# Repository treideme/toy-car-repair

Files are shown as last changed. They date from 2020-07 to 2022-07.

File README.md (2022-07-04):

# Mercedes Toy Repair

This repo contains schematics, drawings, and firmware of the controller
for my sons broken Mercedes.

See [my blogpost](https://www.reidemeister.com/?p=465) for more information.

---- 
Pull requests are welcome. For major changes, please open an issue first to discuss what you would like to change.

## License
[MIT](LICENSE.md)

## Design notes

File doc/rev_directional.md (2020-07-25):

# Reverse Engineering the Directional Controller

This module seems to take care of the directional control of the
car. 

Directional Controller

It has three buttons. The center button disables directional
control. The front and the back button set the direction.

There are two LEDs next to the buttons that indicate the direction.

The board is supplied through J1. The pinout, starting from the J1
marking seems to be as follows.

| Pin # | Signal | Level | Cable Color
|---|---|---|---
| 1 | GND | 0 V | Black
| 2 | Power  | 5 V | White
| 3 | Backward | 0 when off, around 2.6V when on | Yellow
| 4 | Forward | 0 when off, around 2.6V when on | Green

----
Back to [Index](INDEX.md)

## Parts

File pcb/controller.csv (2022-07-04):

Reference | Quantity | Value | Footprint | Datasheet | MFRPN | LCSC | Manufacturer | Description | Height | Manufacturer_Name | Manufacturer_Part_Number | Arrow Part Number | Arrow Price/Stock | Mouser Part Number | Mouser Price/Stock | Manufacture | MFNPN
C1 C14 C15 C16 C17 C2 C20 C21 C3 C4 C5 C6 C8 C9 | 14 | 100nF | Capacitors_SMD:C_0603_HandSoldering |  | GCM188R71C104KA37D | C184760 | Murata | , | , | , | , | ,
C12 C13 | 2 | C | Capacitors_SMD:C_0603_HandSoldering |  | CC0603JRX7R6BB474 | C519557 | YAGEO | , | , | , | , | ,
C18 | 1 | 1000uF | Capacitors_SMD:CP_Elec_10x10 |  | EEEFC1A102AP | C401617 | PANASONIC | , | , | , | , | ,
C19 C22 C23 | 3 | 10uF | Capacitors_SMD:C_0805_HandSoldering |  | GRM21BR61C106KE15L | C77075 | Murata Electronics | , | , | , | , | ,
C10 C11 C7 | 3 | 2.2uF | Capacitors_SMD:C_0603_HandSoldering |  | GRM188B31A225KE33D | C85991 | Murata | , | , | , | , | ,
F1 | 1 | 16V 10A | Fuse_Holders_and_Fuses:Fuse_SMD2920 |  | 2920L500/16MR | C207091 | Littlefuse | , | , | , | , | ,
J1 | 1 | Steering | Connectors_JST:JST_XH_B05B-XH-A_05x2.50mm_Straight |  | B5B-XH-A(LF)(SN) | C157991 | JST | , | , | , | , | ,
J10 | 1 | SPK_L_OUT | Connectors_JST:JST_XH_B02B-XH-A_02x2.50mm_Straight |  | B2B-XH-A(LF)(SN) | C158012 | JST | , | , | , | , | ,
J11 | 1 | Batt | Connectors_JST:JST_VH_B2P-VH-B_2x3.96mm_Vertical |  | B2P-VH(LF)(SN) | C160315 | JST | , | , | , | , | ,
J12 | 1 | Motor | Connectors_JST:JST_VH_B2P-VH-B_2x3.96mm_Vertical |  | B2P-VH(LF)(SN) | C160315 | JST | , | , | , | , | ,
J13 | 1 | ACC | Connectors_JST:JST_XH_B02B-XH-A_02x2.50mm_Straight |  | B2B-XH-A(LF)(SN) | C158012 | JST | , | , | , | , | ,
J2 | 1 | Volume | Connectors_JST:JST_XH_B03B-XH-A_03x2.50mm_Straight |  | ,C144394" | JST | , | , | , | , | ,B3B-XH-A(LF)(SN)"
J3 | 1 | Light | Connectors_JST:JST_XH_B02B-XH-A_02x2.50mm_Straight |  | B2B-XH-A(LF)(SN) | C158012 | JST | , | , | , | , | ,
J4 | 1 | Gas_In | Connectors_JST:JST_XH_B02B-XH-A_02x2.50mm_Straight |  | B2B-XH-A(LF)(SN) | C158012 | JST | , | , | , | , | ,
J5 | 1 | Direction | Connectors_JST:JST_XH_B04B-XH-A_04x2.50mm_Straight |  | B4B-XH-A(LF)(SN) | C144395 | JST | , | , | , | , | ,
J6 | 1 | Light_Out | Connectors_JST:JST_XH_B02B-XH-A_02x2.50mm_Straight |  | B2B-XH-A(LF)(SN) | C158012 | JST | , | , | , | , | ,
J7 | 1 | LED_Out | Connectors_JST:JST_XH_B02B-XH-A_02x2.50mm_Straight |  | B2B-XH-A(LF)(SN) | C158012 | JST | , | , | , | , | ,
J8 | 1 | uSD | Connectors_Card:Hirose_DM3AT-SF-PEJM5 |  | DM3AT-SF-PEJM5 | C114218 | Hirose | , | , | , | , | ,
J9 | 1 | SPK_R_OUT | Connectors_JST:JST_XH_B02B-XH-A_02x2.50mm_Straight |  | B2B-XH-A(LF)(SN) | C158012 | JST | , | , | , | , | ,
JP1 | 1 | 20021221-00010C4LF | lib:20021221-00010C4LF
JP2 | 1 | Jumper_NO_Small | lib:SolderJumper-2_P1.3mm_Open_Pad1.0x1.5mm
K1 K2 K3 | 3 | JQ1P-5V-F | lib:JQ1P5VF | https://www3.panasonic.biz/ac/e_download/control/relay/power/catalog/mech_eng_jq.pdf?via=ok | ,C58271" | ,Electromechanical Relay 5VDC 62.5Ohm 10(NO)/3(NC)A SPDT (20x10x16)mm THT Power Relay" | 16 | Panasonic | JQ1P-5V-F | JQ1P-5V-F | https://www.arrow.com/en/products/jq1p-5v-f/panasonic | 769-JQ1P-5V-F | https://www.mouser.co.uk/ProductDetail/Panasonic-Industrial-Devices/JQ1P-5V-F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 | ,
M1 M2 M3 M4 | 4 | M3 | Mounting_Holes:MountingHole_3.2mm_M3_Pad
R1 R2 | 2 | 100K | Resistors_SMD:R_0603_HandSoldering |  | ERJUP3J104V | C491207 | Panasonic | , | , | , | , | ,
R18 R19 R20 R21 R22 R23 R24 | 7 | 22 | Resistors_SMD:R_0603_HandSoldering |  | ERJ3GEYJ220V | C278638 | , | , | , | , | ,Panasonic" | R25 R26 R27 R28 R29 R30 R31 ,7,47K" | Resistors_SMD:R_0603_HandSoldering |  | ERJ3GEYJ473V | C278642 | , | , | , | , | ,Panasonic" | R3 R4 ,2,10K" | Resistors_SMD:R_0603_HandSoldering | ERJ3RBD1002V | C191318 | PANASONIC | , | , | , | , | ,
R10 R11 R12 R13 R14 R15 R16 R17 R5 R6 R7 R8 R9 | 13 | 220 | Resistors_SMD:R_0603_HandSoldering |  | ERJ3GEYJ221V | C403454 | , | , | , | , | ,Panasonic" | RV1 RV2 ,2,50K" | lib:TRIM_3314J-1-202E |  | 3314J-1-503E | C50895 | BOURNS | , | , | , | , | ,
U1 | 1 | ULN2803A | Housings_SOIC:SOIC-18W_7.5x11.6mm_Pitch1.27mm |  | ULN2803ADWR | C9683 | Texas Instruments | , | , | , | , | ,
U2 | 1 | STM32F405RGTx | Housings_QFP:LQFP-64_10x10mm_Pitch0.5mm |  | STM32F405RGT6 | C15742 | STMicroelectronics | , | , | , | , | ,
U3 | 1 | PAM8403DR | lib:SOIC127P605X150-16N | Diodes | PAM8403D | C348830 | Diodes Inc | , | , | , | , | ,
U4 | 1 | LD1085D2T33R | TO_SOT_Packages_SMD:TO-263-2 |  | LD1085D2T33R | C7913 | STMicroelectronics | , | , | , | , | ,

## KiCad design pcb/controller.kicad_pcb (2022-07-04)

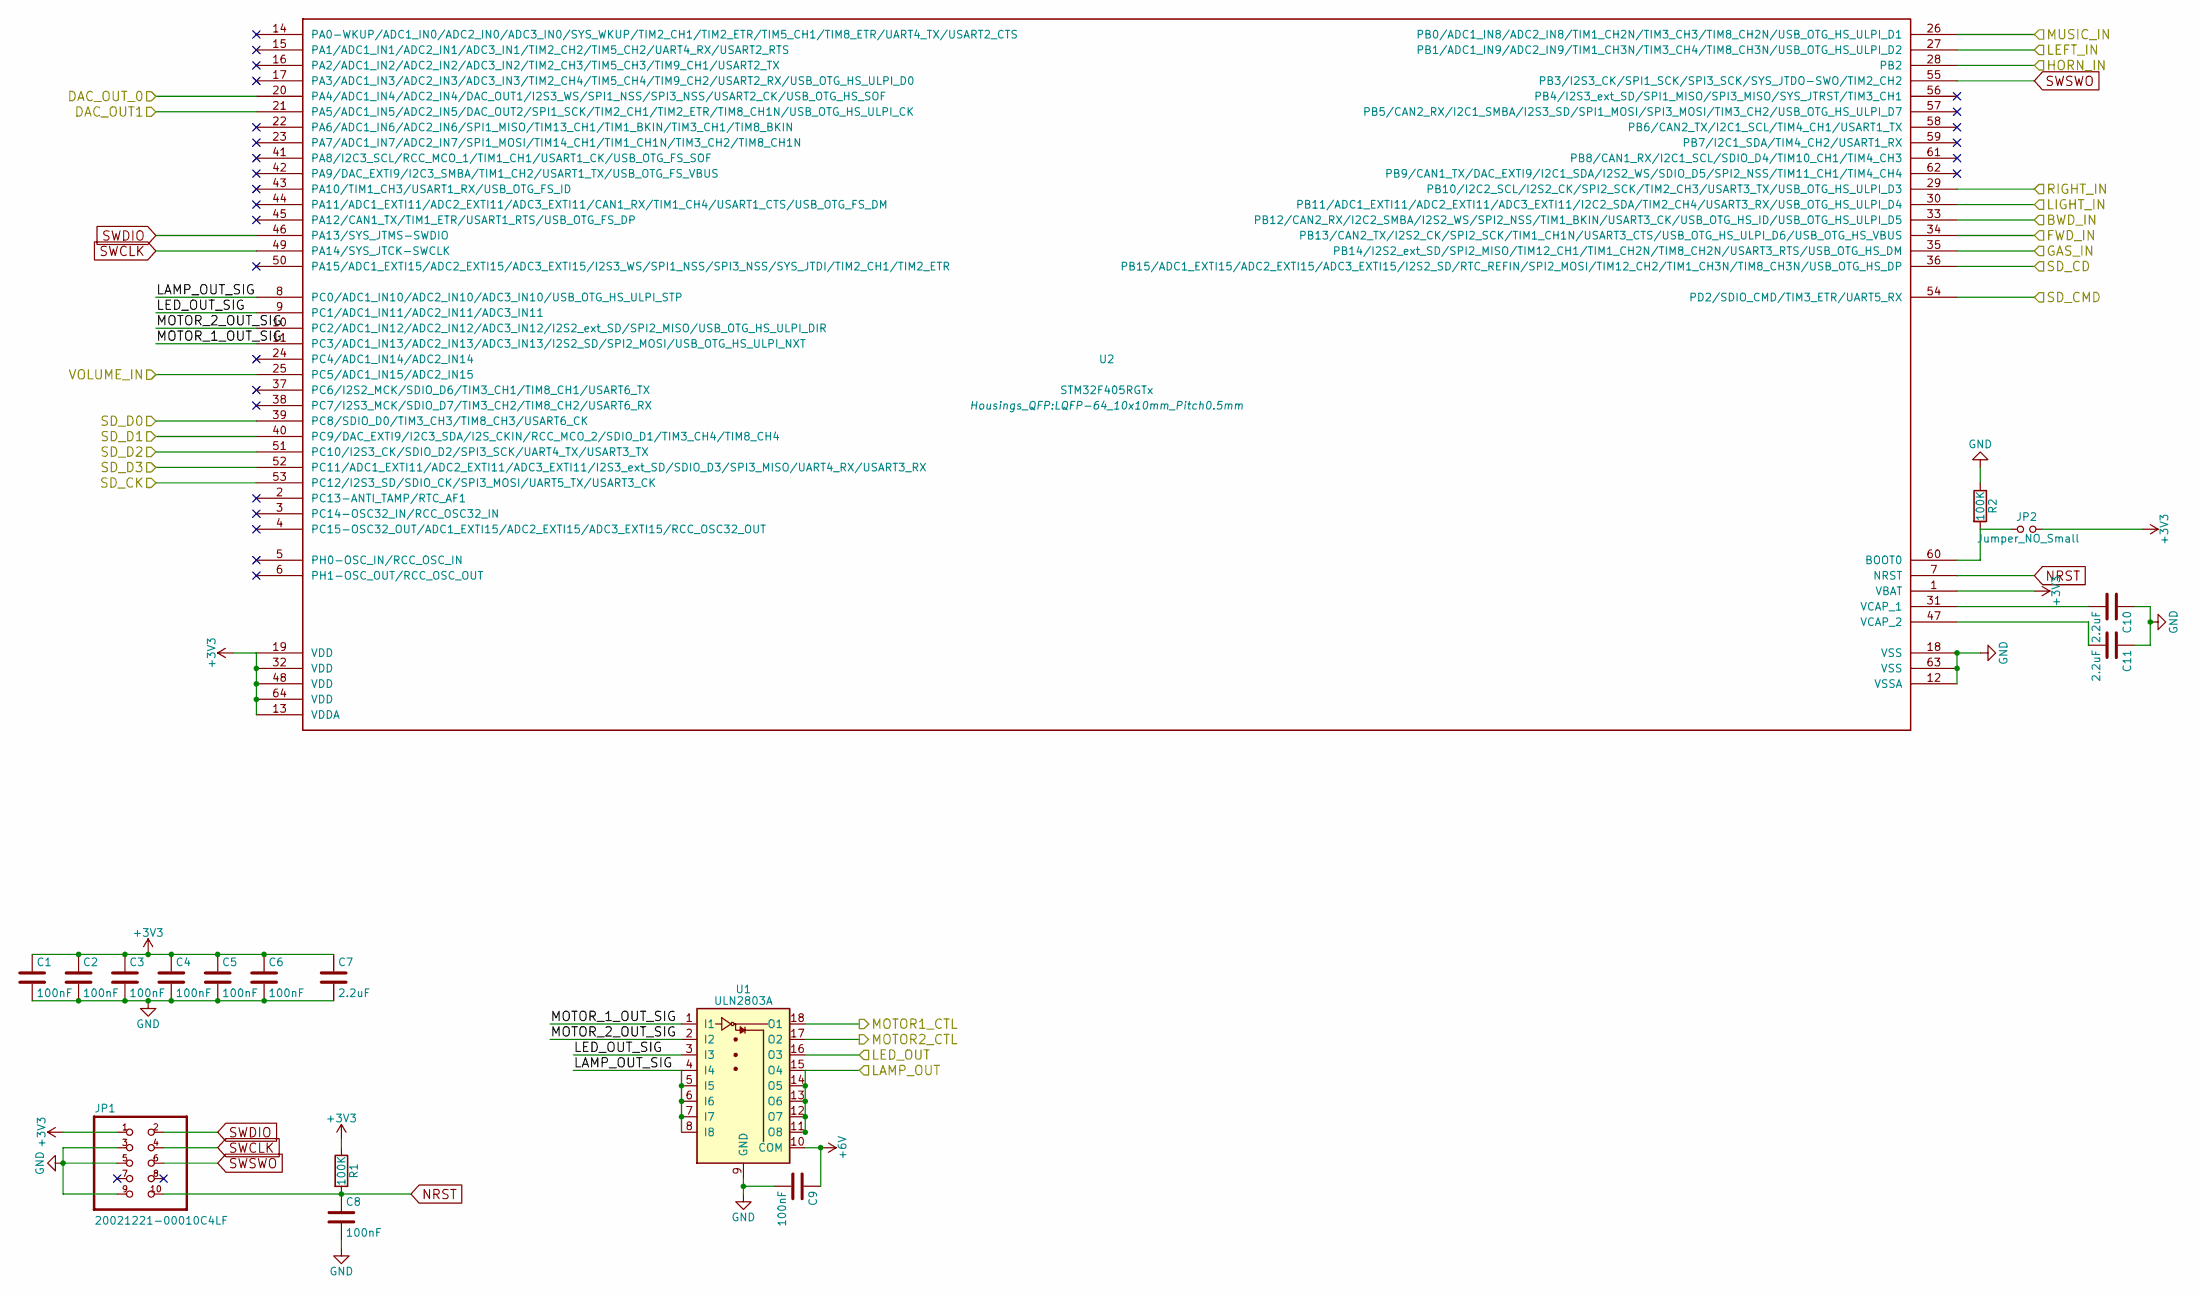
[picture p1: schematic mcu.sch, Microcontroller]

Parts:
C1, C2, C3, C4, C5, C6, C8, C9: 100nF; C_0603_HandSoldering; MFRPN GCM188R71C104KA37D; LCSC C184760
C7, C10, C11: 2.2uF; C_0603_HandSoldering; MFRPN GRM188B31A225KE33D; LCSC C85991
JP1: 20021221-00010C4LF
JP2: Jumper_NO_Small; SolderJumper-2_P1.3mm_Open_Pad1.0x1.5mm
R1, R2: 100K; R_0603_HandSoldering; MFRPN ERJUP3J104V; LCSC C491207
U1: ULN2803A; SOIC-18W_7.5x11.6mm_Pitch1.27mm; MFRPN ULN2803ADWR; LCSC C9683
U2: STM32F405RGTx; LQFP-64_10x10mm_Pitch0.5mm; MFRPN STM32F405RGT6; LCSC C15742

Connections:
+3V3: C1.1, C2.1, C3.1, C4.1, C5.1, C6.1, C7.1, JP1.1, JP2.2, R1.1, U2.1 (VBAT), U2.13 (VDDA), U2.19 (VDD), U2.32 (VDD), U2.48 (VDD), U2.64 (VDD); also elsewhere on the board
+6V: C9.1, U1.10 (COM); also elsewhere on the board
/External/BACKWARD_IN: U2.33 (PB12/CAN2_RX/I2C2_SMBA/I2S2_WS/SPI2_NSS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); also elsewhere on the board
/External/FORWARD_IN: U2.34 (PB13/CAN2_TX/I2S2_CK/SPI2_SCK/TIM1_CH1N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); also elsewhere on the board
/External/GAS_IN: U2.35 (PB14/I2S2_ext_SD/SPI2_MISO/TIM12_CH1/TI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); also elsewhere on the board
/External/HORN_IN: U2.28 (PB2); also elsewhere on the board
/External/LED_OUT: U1.16 (O3); also elsewhere on the board
/External/LEFT_IN: U2.27 (PB1/ADC1_IN9/ADC2_IN9/TIM1_CH3N/TIM3_CH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); also elsewhere on the board
/External/LIGHT_IN: U2.30 (PB11/ADC1_EXTI11/ADC2_EXTI11/ADC3_EXTI1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); also elsewhere on the board
/External/MUSIC_IN: U2.26 (PB0/ADC1_IN8/ADC2_IN8/TIM1_CH2N/TIM3_CH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); also elsewhere on the board
/External/RIGHT_IN: U2.29 (PB10/I2C2_SCL/I2S2_CK/SPI2_SCK/TIM2_CH3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); also elsewhere on the board
/External/SD_CMD: U2.54 (PD2/SDIO_CMD/TIM3_ETR/UART5_RX); also elsewhere on the board
/External/SD_D0: U2.39 (PC8/SDIO_D0/TIM3_CH3/TIM8_CH3/USART6_CK); also elsewhere on the board
/External/SD_D1: U2.40 (PC9/DAC_EXTI9/I2C3_SDA/I2S_CKIN/RCC_MCO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); also elsewhere on the board
/External/SD_D2: U2.51 (PC10/I2S3_CK/SDIO_D2/SPI3_SCK/UART4_TX/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); also elsewhere on the board
/External/SD_D3: U2.52 (PC11/ADC1_EXTI11/ADC2_EXTI11/ADC3_EXTI1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); also elsewhere on the board
/External/VOLUME_IN: U2.25 (PC5/ADC1_IN15/ADC2_IN15); also elsewhere on the board
/Microcontroller/DAC_OUT1: U2.21 (PA5/ADC1_IN5/ADC2_IN5/DAC_OUT2/SPI1_SCK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); also elsewhere on the board
/Microcontroller/DAC_OUT_0: U2.20 (PA4/ADC1_IN4/ADC2_IN4/DAC_OUT1/I2S3_WS/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); also elsewhere on the board
/Microcontroller/LAMP_OUT: U1.11 (O8), U1.12 (O7), U1.13 (O6), U1.14 (O5), U1.15 (O4); also elsewhere on the board
/Microcontroller/LAMP_OUT_SIG: U1.4 (I4), U1.5 (I5), U1.6 (I6), U1.7 (I7), U1.8 (I8), U2.8 (PC0/ADC1_IN10/ADC2_IN10/ADC3_IN10/USB_O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)
/Microcontroller/LED_OUT_SIG: U1.3 (I3), U2.9 (PC1/ADC1_IN11/ADC2_IN11/ADC3_IN11)
/Microcontroller/MOTOR1_CTL: U1.18 (O1); also elsewhere on the board
/Microcontroller/MOTOR2_CTL: U1.17 (O2); also elsewhere on the board
/Microcontroller/MOTOR_1_OUT_SIG: U1.1 (I1), U2.11 (PC3/ADC1_IN13/ADC2_IN13/ADC3_IN13/I2S2_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)
/Microcontroller/MOTOR_2_OUT_SIG: U1.2 (I2), U2.10 (PC2/ADC1_IN12/ADC2_IN12/ADC3_IN12/I2S2_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)
/Microcontroller/SD_CD: U2.36 (PB15/ADC1_EXTI15/ADC2_EXTI15/ADC3_EXTI1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); also elsewhere on the board
/Microcontroller/SD_CK: U2.53 (PC12/I2S3_SD/SDIO_CK/SPI3_MOSI/UART5_TX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); also elsewhere on the board
GND: C1.2, C2.2, C3.2, C4.2, C5.2, C6.2, C7.2, C8.2, C9.2, C10.1, C11.1, JP1.3, JP1.5, JP1.9, R2.1, U1.9 (GND), U2.12 (VSSA), U2.18 (VSS), U2.63 (VSS); also elsewhere on the board
NRST: C8.1, JP1.10, R1.2, U2.7 (NRST)
unnamed: C10.2, U2.31 (VCAP_1)
unnamed: C11.2, U2.47 (VCAP_2)
unnamed: JP2.1, R2.2, U2.60 (BOOT0)
SWCLK: JP1.4, U2.49 (PA14/SYS_JTCK-SWCLK)
SWDIO: JP1.2, U2.46 (PA13/SYS_JTMS-SWDIO)
SWSWO: JP1.6, U2.55 (PB3/I2S3_CK/SPI1_SCK/SPI3_SCK/SYS_JTDO-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)

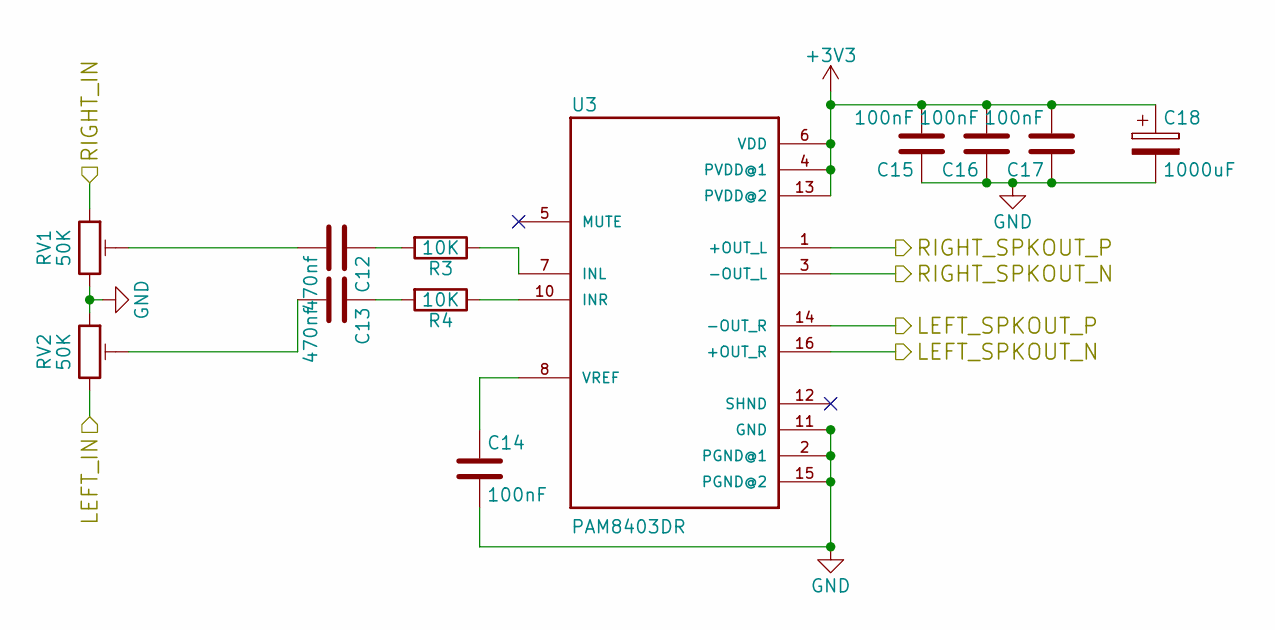
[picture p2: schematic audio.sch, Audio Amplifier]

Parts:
C12, C13: 470nf; C_0603_HandSoldering; MFRPN CC0603JRX7R6BB474; LCSC C519557
C14, C15, C16, C17: 100nF; C_0603_HandSoldering; MFRPN GCM188R71C104KA37D; LCSC C184760
C18: 1000uF; CP_Elec_10x10; MFRPN EEEFC1A102AP; LCSC C401617
R3, R4: 10K; R_0603_HandSoldering; MFRPN ERJ3RBD1002V; LCSC C191318
RV1, RV2: 50K; TRIM_3314J-1-202E; MFRPN 3314J-1-503E; LCSC C50895
U3: PAM8403DR; SOIC127P605X150-16N; MFRPN PAM8403D; LCSC C348830

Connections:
+3V3: C15.2, C16.2, C17.2, C18.1, U3.4 (PVDD@1), U3.6 (VDD), U3.13 (PVDD@2); also elsewhere on the board
/Audio/LEFT_SPKOUT_N: U3.16 (+OUT_R); also elsewhere on the board
/Audio/LEFT_SPKOUT_P: U3.14 (-OUT_R); also elsewhere on the board
/Audio/RIGHT_SPKOUT_N: U3.3 (-OUT_L); also elsewhere on the board
/Audio/RIGHT_SPKOUT_P: U3.1 (+OUT_L); also elsewhere on the board
/Microcontroller/DAC_OUT1: RV2.3; also elsewhere on the board
/Microcontroller/DAC_OUT_0: RV1.1; also elsewhere on the board
GND: C14.2, C15.1, C16.1, C17.1, C18.2, RV1.3, RV2.1, U3.2 (PGND@1), U3.11 (GND), U3.15 (PGND@2); also elsewhere on the board
unnamed: C12.1, R3.2
unnamed: C12.2, RV1.2
unnamed: C13.1, R4.2
unnamed: C13.2, RV2.2
unnamed: C14.1, U3.8 (VREF)
unnamed: R3.1, U3.7 (INL)
unnamed: R4.1, U3.10 (INR)

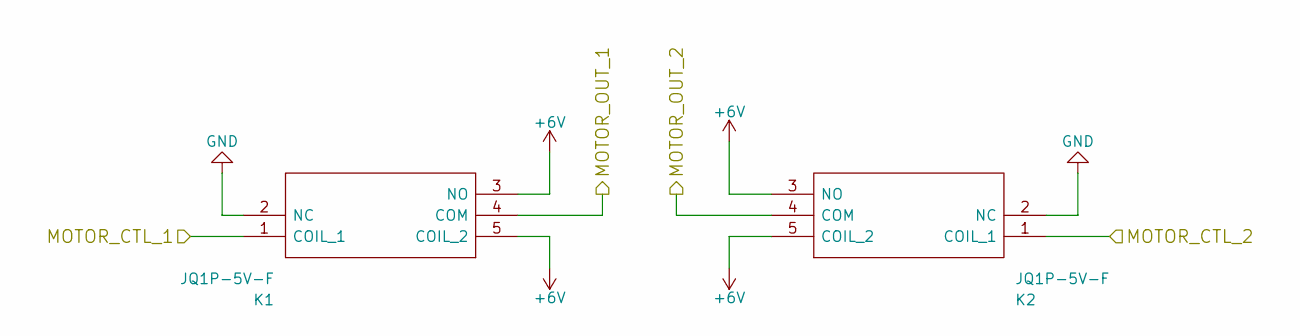
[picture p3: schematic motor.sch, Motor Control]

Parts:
K1, K2: JQ1P-5V-F; JQ1P5VF; Manufacturer_Part_Number JQ1P-5V-F; Mouser Part Number 769-JQ1P-5V-F

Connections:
+6V: K1.3 (NO), K1.5 (COIL_2), K2.3 (NO), K2.5 (COIL_2); also elsewhere on the board
/External/MOTOR_OUT_1: K1.4 (COM); also elsewhere on the board
/External/MOTOR_OUT_2: K2.4 (COM); also elsewhere on the board
/Microcontroller/MOTOR1_CTL: K1.1 (COIL_1); also elsewhere on the board
/Microcontroller/MOTOR2_CTL: K2.1 (COIL_1); also elsewhere on the board
GND: K1.2 (NC), K2.2 (NC); also elsewhere on the board

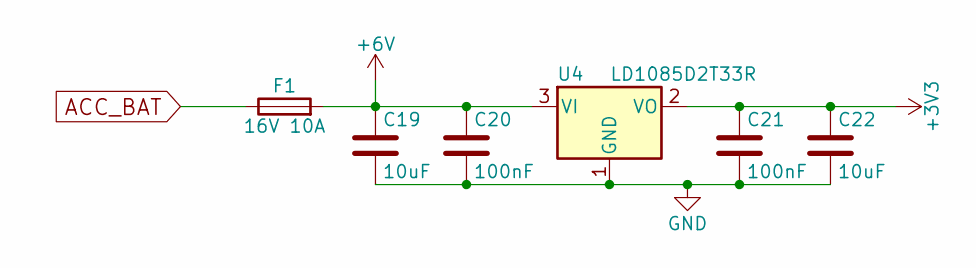
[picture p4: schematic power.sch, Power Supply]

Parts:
C19, C22: 10uF; C_0805_HandSoldering; MFRPN GRM21BR61C106KE15L; LCSC C77075
C20, C21: 100nF; C_0603_HandSoldering; MFRPN GCM188R71C104KA37D; LCSC C184760
F1: 16V 10A; Fuse_SMD2920; MFRPN 2920L500/16MR; LCSC C207091
U4: LD1085D2T33R; TO-263-2; MFRPN LD1085D2T33R; LCSC C7913

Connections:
+3V3: C21.1, C22.1, U4.2 (VO); also elsewhere on the board
+6V: C19.1, C20.1, F1.2, U4.3 (VI); also elsewhere on the board
ACC_BAT: F1.1; also elsewhere on the board
GND: C19.2, C20.2, C21.2, C22.2, U4.1 (GND); also elsewhere on the board

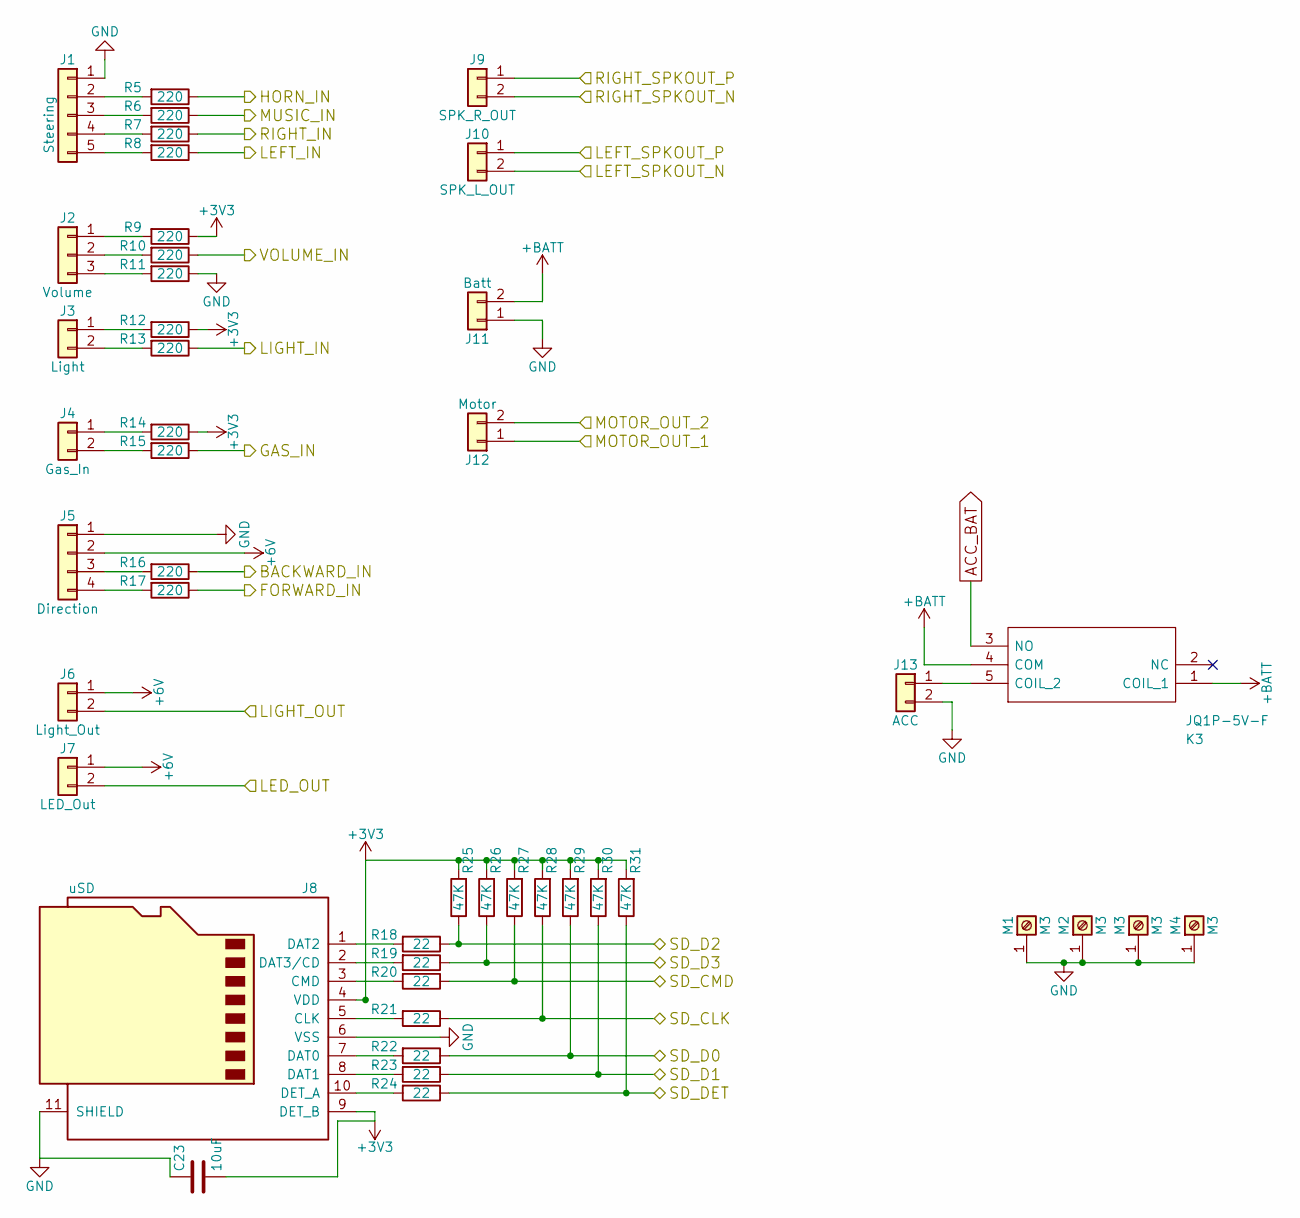
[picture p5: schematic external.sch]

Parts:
C23: 10uF; C_0805_HandSoldering; MFRPN GRM21BR61C106KE15L; LCSC C77075
J1: Steering; JST_XH_B05B-XH-A_05x2.50mm_Straight; MFRPN B5B-XH-A(LF)(SN); LCSC C157991
J2: Volume; JST_XH_B03B-XH-A_03x2.50mm_Straight; LCSC C144394
J3: Light; JST_XH_B02B-XH-A_02x2.50mm_Straight; MFRPN B2B-XH-A(LF)(SN); LCSC C158012
J4: Gas_In; JST_XH_B02B-XH-A_02x2.50mm_Straight; MFRPN B2B-XH-A(LF)(SN); LCSC C158012
J5: Direction; JST_XH_B04B-XH-A_04x2.50mm_Straight; MFRPN B4B-XH-A(LF)(SN); LCSC C144395
J6: Light_Out; JST_XH_B02B-XH-A_02x2.50mm_Straight; MFRPN B2B-XH-A(LF)(SN); LCSC C158012
J7: LED_Out; JST_XH_B02B-XH-A_02x2.50mm_Straight; MFRPN B2B-XH-A(LF)(SN); LCSC C158012
J8: uSD; Hirose_DM3AT-SF-PEJM5; MFRPN DM3AT-SF-PEJM5; LCSC C114218
J9: SPK_R_OUT; JST_XH_B02B-XH-A_02x2.50mm_Straight; MFRPN B2B-XH-A(LF)(SN); LCSC C158012
J10: SPK_L_OUT; JST_XH_B02B-XH-A_02x2.50mm_Straight; MFRPN B2B-XH-A(LF)(SN); LCSC C158012
J11: Batt; JST_VH_B2P-VH-B_2x3.96mm_Vertical; MFRPN B2P-VH(LF)(SN); LCSC C160315
J12: Motor; JST_VH_B2P-VH-B_2x3.96mm_Vertical; MFRPN B2P-VH(LF)(SN); LCSC C160315
J13: ACC; JST_XH_B02B-XH-A_02x2.50mm_Straight; MFRPN B2B-XH-A(LF)(SN); LCSC C158012
K3: JQ1P-5V-F; JQ1P5VF; Manufacturer_Part_Number JQ1P-5V-F; Mouser Part Number 769-JQ1P-5V-F
M1, M2, M3, M4: M3; MountingHole_3.2mm_M3_Pad
R5, R6, R7, R8, R9, R10, R11, R12, R13, R14, R15, R16, R17: 220; R_0603_HandSoldering; MFRPN ERJ3GEYJ221V; LCSC C403454
R18, R19, R20, R21, R22, R23, R24: 22; R_0603_HandSoldering; MFRPN ERJ3GEYJ220V; LCSC C278638
R25, R26, R27, R28, R29, R30, R31: 47K; R_0603_HandSoldering; MFRPN ERJ3GEYJ473V; LCSC C278642

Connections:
+3V3: C23.2, J8.4 (VDD), J8.9 (DET_B), R9.1, R12.1, R14.1, R25.2, R26.2, R27.2, R28.2, R29.2, R30.2, R31.2; also elsewhere on the board
+6V: J5.2, J6.1, J7.1; also elsewhere on the board
+BATT: J11.2, K3.1 (COIL_1), K3.4 (COM)
/Audio/LEFT_SPKOUT_N: J10.2; also elsewhere on the board
/Audio/LEFT_SPKOUT_P: J10.1; also elsewhere on the board
/Audio/RIGHT_SPKOUT_N: J9.2; also elsewhere on the board
/Audio/RIGHT_SPKOUT_P: J9.1; also elsewhere on the board
/External/BACKWARD_IN: R16.1; also elsewhere on the board
/External/FORWARD_IN: R17.1; also elsewhere on the board
/External/GAS_IN: R15.1; also elsewhere on the board
/External/HORN_IN: R5.1; also elsewhere on the board
/External/LED_OUT: J7.2; also elsewhere on the board
/External/LEFT_IN: R8.1; also elsewhere on the board
/External/LIGHT_IN: R13.1; also elsewhere on the board
/External/MOTOR_OUT_1: J12.1; also elsewhere on the board
/External/MOTOR_OUT_2: J12.2; also elsewhere on the board
/External/MUSIC_IN: R6.1; also elsewhere on the board
/External/RIGHT_IN: R7.1; also elsewhere on the board
/External/SD_CMD: R20.1, R27.1; also elsewhere on the board
/External/SD_D0: R22.1, R29.1; also elsewhere on the board
/External/SD_D1: R23.1, R30.1; also elsewhere on the board
/External/SD_D2: R18.1, R25.1; also elsewhere on the board
/External/SD_D3: R19.1, R26.1; also elsewhere on the board
/External/VOLUME_IN: R10.1; also elsewhere on the board
/Microcontroller/LAMP_OUT: J6.2; also elsewhere on the board
/Microcontroller/SD_CD: R24.1, R31.1; also elsewhere on the board
/Microcontroller/SD_CK: R21.1, R28.1; also elsewhere on the board
ACC_BAT: K3.3 (NO); also elsewhere on the board
GND: C23.1, J1.1, J5.1, J8.6 (VSS), J8.11 (SHIELD), J11.1, J13.2, M1.1, M2.1, M3.1, M4.1, R11.1; also elsewhere on the board
unnamed: J1.2, R5.2
unnamed: J1.3, R6.2
unnamed: J1.4, R7.2
unnamed: J1.5, R8.2
unnamed: J2.1, R9.2
unnamed: J2.2, R10.2
unnamed: J2.3, R11.2
unnamed: J3.1, R12.2
unnamed: J3.2, R13.2
unnamed: J4.1, R14.2
unnamed: J4.2, R15.2
unnamed: J5.3, R16.2
unnamed: J5.4, R17.2
unnamed: J8.1 (DAT2), R18.2
unnamed: J8.2 (DAT3/CD), R19.2
unnamed: J8.3 (CMD), R20.2
unnamed: J8.5 (CLK), R21.2
unnamed: J8.7 (DAT0), R22.2
unnamed: J8.8 (DAT1), R23.2
unnamed: J8.10 (DET_A), R24.2
unnamed: J13.1, K3.5 (COIL_2)

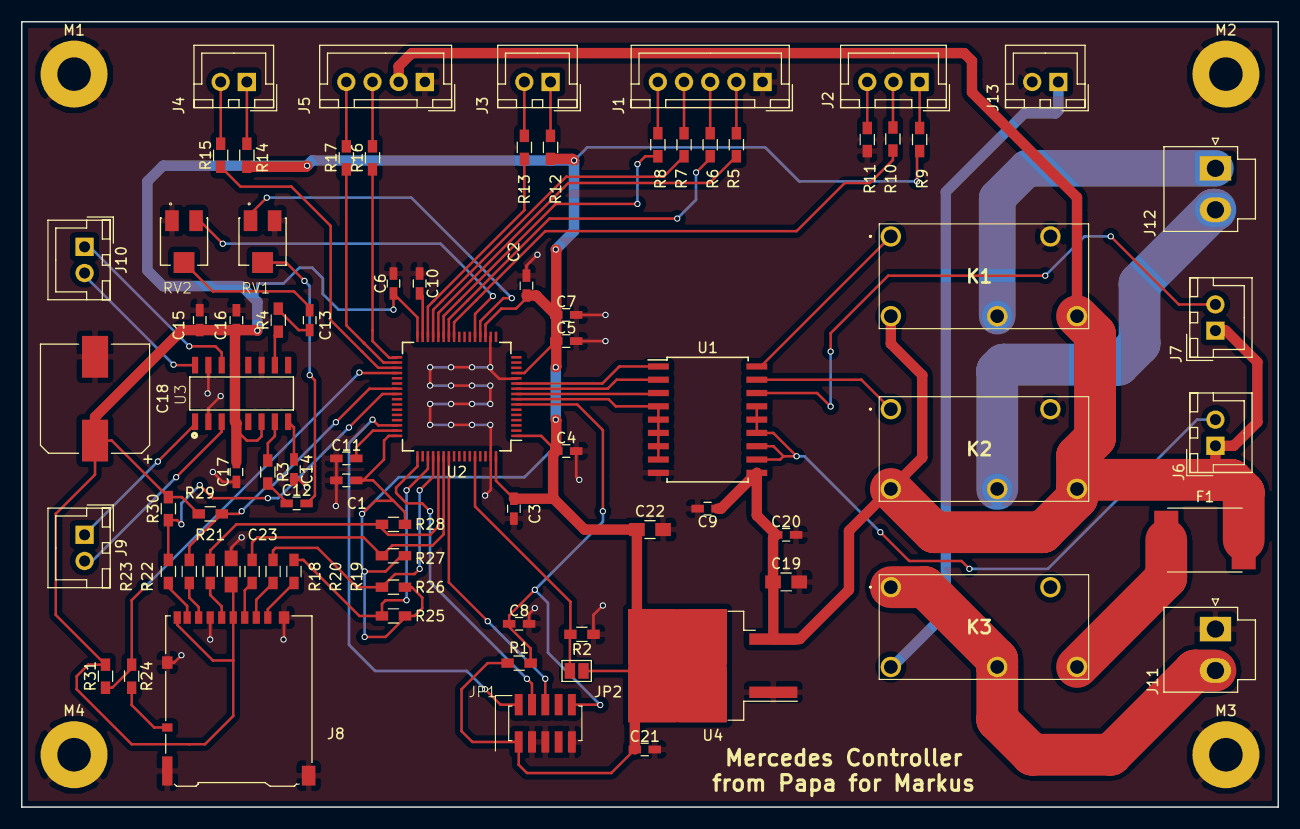
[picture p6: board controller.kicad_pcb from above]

Board: 2 copper layers, 120.0 x 75.0 mm, 83 parts (0 on the bottom side), 72 nets.

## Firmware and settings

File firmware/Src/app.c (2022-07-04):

/**
 * Main Application Entry
 * @author Thomas Reidemeister
 * @file app.c
 */
#include <stdio.h>
#include <stdlib.h>
#include <stdint.h>
#include <stdbool.h>
#include <string.h>
#include "main.h"
#include "dac.h"
#include "fatfs.h"
#include "sdio.h"
#include "gpio.h"

#include "bsp_driver_sd.h"
#include "control.h"
#include "tim.h"
#include "macro.h"

#define RSIZE 32768

extern void SystemClock_Config(void); // Not exported by CubeMX
static char semihosting_stdout_buf[16];
static char semihosting_stderr_buf[16];

/**
 * Override SD detection. SDIO driver assumes pull to ground, however,
 * by accident permanently pulled high.
 * @return
 */
uint8_t BSP_SD_IsDetected(void) {
  return SD_PRESENT;
}

/**
 * @brief  The application entry point.
 * @retval int
 */
int main(void) {
  //Disable STDOUT buffering. Otherwise nothing will be printed before
  //a newline character or when the buffer is flushed. This MUST be done
  //before any writes to STDOUT to have any effect...
  setvbuf(stdout, semihosting_stdout_buf, _IOLBF, sizeof(semihosting_stdout_buf));
  setvbuf(stderr, semihosting_stderr_buf, _IOLBF, sizeof(semihosting_stderr_buf));

  /* Reset of all peripherals, Initializes the Flash interface and the Systick. */
  HAL_Init();

  /* Configure the system clock */
  SystemClock_Config();

  /* Initialize all configured peripherals */
  MX_GPIO_Init();
  MX_SDIO_SD_Init();
  MX_DAC_Init();
  MX_FATFS_Init();
  MX_TIM10_Init();

  /* Check that FatFS was properly initialized */
  if(retSD != 0) {
    printf("Error Initializing FatFS\r\n");
    for(;;);
  }

  FRESULT res;

  if((res = f_mount(&SDFatFS, SDPath, 1)) != FR_OK) {
    printf("Error Mounting uSD: %i\r\n", res);
    for(;;);
  }
  HAL_TIM_Base_Start_IT(&htim10);
  printf(" Path: %s\r\n", SDPath);

  if(!controls_init()) {
    printf("Error initialising controls\r\n");
    for(;;);
  }
  printf("Starting timer\r\n");
  HAL_TIM_Base_Start_IT(&htim10);
  /* Infinite loop */
  for (;;) {
    controls_update();
  }

}

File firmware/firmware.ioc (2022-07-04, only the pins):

Mcu.UserName=STM32F405RGTx
PC12.Signal=SDIO_CK
PC10.Signal=SDIO_D2
PB14.GPIO_Label=GAS_BTN
PC0.GPIO_Label=LAMP_OUT
PB0.GPIO_Label=MUSIC_BTN
PB13.GPIO_Label=FWD_BTN
PB11.Signal=GPIO_Input
PB13.Signal=GPIO_Input
PB15.Signal=GPIO_Input
PC3.Signal=GPIO_Output
PB2.Signal=GPIO_Input
PB12.GPIO_Label=BWD_BTN
PB1.GPIO_Label=LEFT_BTN
PB1.Signal=GPIO_Input
PC5.Signal=ADCx_IN15
PC2.GPIO_Label=MOTOR_2
PC11.Signal=SDIO_D3
PC8.Signal=SDIO_D0
PC2.Signal=GPIO_Output
PB11.GPIO_Label=LIGHT_BTN
PC0.Signal=GPIO_Output
PA13.Signal=SYS_JTMS-SWDIO
PB10.GPIO_Label=RIGHT_BTN
PB10.Signal=GPIO_Input
PB14.Signal=GPIO_Input
PA5.Signal=COMP_DAC2_group
PB15.GPIO_Label=SDIO_CD
PC1.GPIO_Label=LED_OUT
PA4.Signal=COMP_DAC1_group
PC5.GPIO_Label=VOLUMNE_IN
PA14.Signal=SYS_JTCK-SWCLK
PB2.GPIO_Label=HORN_BTN
PC3.GPIO_Label=MOTOR_1
PC9.Signal=SDIO_D1
PD2.Signal=SDIO_CMD
PB0.Signal=GPIO_Input
PC1.Signal=GPIO_Output
PB12.Signal=GPIO_Input

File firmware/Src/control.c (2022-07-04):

#include <stdio.h>
#include <string.h>
#include <stdlib.h>

#include "control.h"
#include "stm32f405xx.h"
#include "macro.h"
#include "audio.h"
#include "ff.h"
#include "dac.h"

static size_t s_total_songs = 0;
static ssize_t s_current_song = 0;
static audio_t player = {0};

int string_ends_with(const char * str, const char * suffix) {
  int str_len = strlen(str);
  int suffix_len = strlen(suffix);

  return (str_len >= suffix_len) && (0 == strcmp(str + (str_len-suffix_len), suffix));
}

void timer_callback(void) {
  uint16_t value = audio_next_12b(&player);
  if(value != 0x800) {
//  printf("TIM: 0x%03X\r\n", value);
    HAL_DAC_SetValue(&hdac, DAC_CHANNEL_1, DAC_ALIGN_12B_R, value);
    HAL_DAC_SetValue(&hdac, DAC_CHANNEL_2, DAC_ALIGN_12B_R, value);
    HAL_DAC_Start(&hdac, DAC_CHANNEL_1);
    HAL_DAC_Start(&hdac, DAC_CHANNEL_2);
  }
}

bool controls_init() {
//  printf("=== List Files ===\r\n");
  FRESULT res;
  DIR dir;
  FILINFO fno;
  res = f_opendir(&dir, "/"); /* Open the directory */
  if (res == FR_OK) {
//    printf("Opened Dir\r\n");
    for (;;) {
      res = f_readdir(&dir, &fno); /* Read a directory item */
      if (res != FR_OK || fno.fname[0] == 0)
        break; /* Break on error or end of dir */
//      printf("%s\r\n", fno.fname);
      if(string_ends_with(fno.fname, ".WAV")) {
//        printf("Found %s\r\n", fno.fname);
        if(strcmp("HORN.WAV", fno.fname) == 0) {
          continue;
        } else if(strcmp("ENGINE.WAV", fno.fname) == 0) {
          continue;
        } else {
//          printf("Found song: %i %s\r\n", s_total_songs, fno.fname);
          s_total_songs++;
        }
      }
    }
    f_closedir(&dir);
    s_current_song = 0;
    audio_playfile(&player, "ENGINE.WAV");
    return true;
  } else {
//    printf("OpenDir failed: %i", res);
    return false;
  }
}

void play_song(size_t index) {
  size_t local_count = 0;
  if(index < s_total_songs) {
//    printf("Valid Index %i\r\n", index);
    FRESULT res;
    DIR dir;
    FILINFO fno;
    res = f_opendir(&dir, "/"); /* Open the directory */
    if (res == FR_OK) {
      for (;;) {
        res = f_readdir(&dir, &fno); /* Read a directory item */
        if (res != FR_OK || fno.fname[0] == 0)
          break; /* Break on error or end of dir */
        if (string_ends_with(fno.fname, ".WAV")) {
          if(strcmp("HORN.WAV", fno.fname) == 0) {
            continue;
          } else if(strcmp("ENGINE.WAV", fno.fname) == 0) {
            continue;
          } else {
            if(local_count == index) {
              audio_playfile(&player, fno.fname);
            }
            local_count++;
          }
        }
      }
      f_closedir(&dir);
    }
  }
}

bool control_handle_input(input_t*p_input) {
  input_state_t state;

  if(HAL_GPIO_ReadPin(p_input->GPIOx, p_input->GPIO_Pin) == GPIO_PIN_SET) {
    if(p_input->inverted) {
      state = INPUT_OFF;
    } else {
      state = INPUT_ON;
    }
  } else {
    if(p_input->inverted) {
      state = INPUT_ON;
    } else {
      state = INPUT_OFF;
    }
  }
  p_input->last_state = p_input->current_state;
  p_input->current_state = state;

  if(p_input->current_state != p_input->last_state) {
    return p_input->on_change(p_input->current_state, p_input->last_state);
  }

  return true;
}

static motor_t s_engine = {
    .forward_set = false,
    .backward_set = false,
    .running = false,

    .GPIO_bridge_1 = MOTOR_1_GPIO_Port,
    .GPIO_bridge_2 = MOTOR_2_GPIO_Port,
    .GPIO_Pin_bridge_1 = MOTOR_1_Pin,
    .GPIO_Pin_bridge_2 = MOTOR_2_Pin,
};

static bool s_on_music(const input_state_t current, const input_state_t before) {
  if(current) {
    if(AUDIO_BUSY(&player)) {
      audio_stop(&player);
//      printf("Audio stopped\r\n");
    } else {
//      printf("Attempting to play %i\r\n", s_current_song);
      play_song(s_current_song);
    }
  }
  return true;
}

static bool s_on_left(const input_state_t current, const input_state_t before) {
  if(current) {
    s_current_song--;
    if(s_current_song < 0) {
      s_current_song = s_total_songs-1;
    }
    play_song(s_current_song);
  }
  return true;
}

static bool s_on_horn(const input_state_t current, const input_state_t before) {
  if(current) {
    audio_playfile(&player, "HORN.WAV");
  }
  return true;
}

static bool s_on_right(const input_state_t current, const input_state_t before) {
  if(current) {
    s_current_song++;
    if(s_current_song >= s_total_songs) {
      s_current_song = 0;
    }
    play_song(s_current_song);
  }
  return true;
}

static bool s_on_light(const input_state_t current, const input_state_t before) {
//  printf("On Light %i %i\r\n", current, before);
  HAL_GPIO_WritePin(LAMP_OUT_GPIO_Port, LAMP_OUT_Pin, current);
  return true;
}

static bool s_on_bwd(const input_state_t current, const input_state_t before) {
//  printf("On BWD %i %i\r\n", current, before);
  s_engine.backward_set = current;
  return true;
}

static bool s_on_fwd(const input_state_t current, const input_state_t before) {
//  printf("On FWD %i %i\r\n", current, before);
  s_engine.forward_set = current;
  return true;
}

static bool s_on_gas(const input_state_t current, const input_state_t before) {
//  printf("On Gas %i %i\r\n", current, before);
  s_engine.running = current;
  return true;
}

static input_t s_inputs[] = {
    // Music button
    {
        .current_state=INPUT_OFF, .last_state=INPUT_OFF,
        .GPIOx=MUSIC_BTN_GPIO_Port, .GPIO_Pin=MUSIC_BTN_Pin,
        .inverted=true,
        .on_change=s_on_music
    },
    {
        .current_state=INPUT_OFF, .last_state=INPUT_OFF,
        .GPIOx=LEFT_BTN_GPIO_Port, .GPIO_Pin=LEFT_BTN_Pin,
        .inverted=true,
        .on_change=s_on_left
    },
    {
        .current_state=INPUT_OFF, .last_state=INPUT_OFF,
        .GPIOx=HORN_BTN_GPIO_Port, .GPIO_Pin=HORN_BTN_Pin,
        .inverted=true,
        .on_change=s_on_horn
    },
    {
        .current_state=INPUT_OFF, .last_state=INPUT_OFF,
        .GPIOx=RIGHT_BTN_GPIO_Port, .GPIO_Pin=RIGHT_BTN_Pin,
        .inverted=true,
        .on_change=s_on_right
    },
    {
        .current_state=INPUT_OFF, .last_state=INPUT_OFF,
        .GPIOx=LIGHT_BTN_GPIO_Port, .GPIO_Pin=LIGHT_BTN_Pin,
        .inverted=false,
        .on_change=s_on_light
    },
    {
        .current_state=INPUT_OFF, .last_state=INPUT_OFF,
        .GPIOx=GAS_BTN_GPIO_Port, .GPIO_Pin=GAS_BTN_Pin,
        .inverted=false,
        .on_change=s_on_gas
    },
    {
        .current_state=INPUT_OFF, .last_state=INPUT_OFF,
        .GPIOx=FWD_BTN_GPIO_Port, .GPIO_Pin=FWD_BTN_Pin,
        .inverted=false,
        .on_change=s_on_fwd
    },
    {
        .current_state=INPUT_OFF, .last_state=INPUT_OFF,
        .GPIOx=BWD_BTN_GPIO_Port, .GPIO_Pin=BWD_BTN_Pin,
        .inverted=false,
        .on_change=s_on_bwd
    },
};
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

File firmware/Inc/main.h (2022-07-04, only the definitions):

#define LAMP_OUT_Pin GPIO_PIN_0
#define LAMP_OUT_GPIO_Port GPIOC
#define LED_OUT_Pin GPIO_PIN_1
#define LED_OUT_GPIO_Port GPIOC
#define MOTOR_2_Pin GPIO_PIN_2
#define MOTOR_2_GPIO_Port GPIOC
#define MOTOR_1_Pin GPIO_PIN_3
#define MOTOR_1_GPIO_Port GPIOC
#define VOLUMNE_IN_Pin GPIO_PIN_5
#define VOLUMNE_IN_GPIO_Port GPIOC
#define MUSIC_BTN_Pin GPIO_PIN_0
#define MUSIC_BTN_GPIO_Port GPIOB
#define LEFT_BTN_Pin GPIO_PIN_1
#define LEFT_BTN_GPIO_Port GPIOB
#define HORN_BTN_Pin GPIO_PIN_2
#define HORN_BTN_GPIO_Port GPIOB
#define RIGHT_BTN_Pin GPIO_PIN_10
#define RIGHT_BTN_GPIO_Port GPIOB
#define LIGHT_BTN_Pin GPIO_PIN_11
#define LIGHT_BTN_GPIO_Port GPIOB
#define BWD_BTN_Pin GPIO_PIN_12
#define BWD_BTN_GPIO_Port GPIOB
#define FWD_BTN_Pin GPIO_PIN_13
#define FWD_BTN_GPIO_Port GPIOB
#define GAS_BTN_Pin GPIO_PIN_14
#define GAS_BTN_GPIO_Port GPIOB
#define SDIO_CD_Pin GPIO_PIN_15
#define SDIO_CD_GPIO_Port GPIOB

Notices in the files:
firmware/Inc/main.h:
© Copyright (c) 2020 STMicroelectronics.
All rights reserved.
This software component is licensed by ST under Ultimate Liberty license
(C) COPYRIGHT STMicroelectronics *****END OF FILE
